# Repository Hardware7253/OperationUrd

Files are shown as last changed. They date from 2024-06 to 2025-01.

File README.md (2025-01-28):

# Operation Urd
A nixie tube clock inspired by the divergence meter from Steins;Gate.

Designed in KiCad and Onshape, programmed in Rust.

tough_pic_1
tough_pic_2
tough pic 3
tough pic 4

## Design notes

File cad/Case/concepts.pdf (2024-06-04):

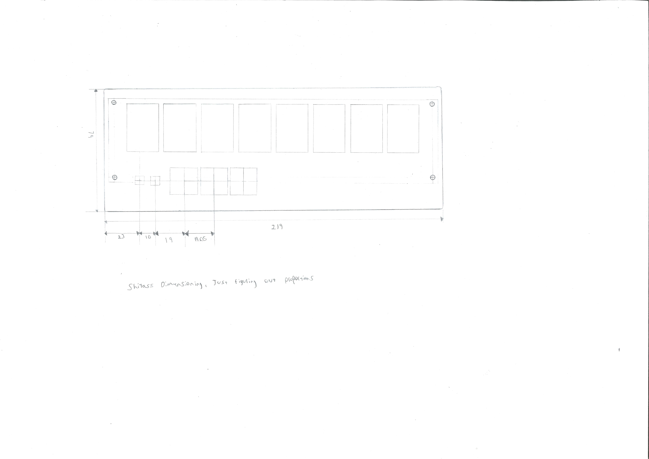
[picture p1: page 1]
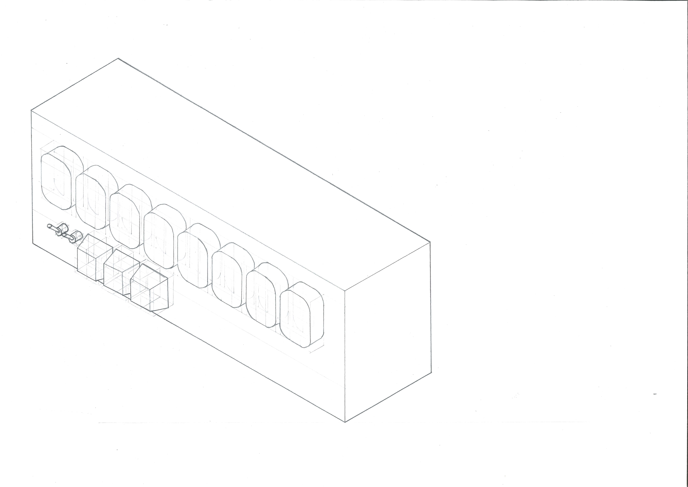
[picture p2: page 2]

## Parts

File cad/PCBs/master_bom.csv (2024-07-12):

Comment | Designator | Footprint | JLCPCB Part # | Mouser Part # | Quantity
10k |  | R_0603_1608Metric | C25804 |  | 24
MMBTA92 |  | SOT-23 | C85182 |  | 8
10k |  | R_1206_3216Metric | C17902 |  | 16
412k |  | R_1206_3216Metric | C323043 |  | 19
MMBTA42 |  | SOT-23 | C466651 |  | 19
100k |  | R_0603_1608Metric | C25803 |  | 1
~ |  | IN12 |  |  | 8
74HC595 |  | SOIC-16_3.9x9.9mm_P1.27mm | C5947 |  | 3
Conn_01x10_Pin |  | IDC-Header_2x05_P2.54mm_Vertical |  |  | 4
MAX1771ESA+T |  | SO-8_3.9x4.9mm_P1.27mm | C407903 |  | 1
68u |  | EEE-FN1E680P | C494823 |  | 1
100n/250v |  | C_1206_3216Metric | C5137643 |  | 1
IRF644PBF |  | TO-220-3_Vertical |  | 844-IRF644PBF | 1
1M5 |  | R_2512_6332Metric | C3013328 |  | 1
100n |  | C_0603_1608Metric | C14663 |  | 7
0.05R |  | R_1206_3216Metric_Pad1.30x1.75mm_HandSolder | C912768 |  | 1
100p/250v |  | C_0805_2012Metric | C2929108 |  | 1
ES2F-E3/5BT |  | D_SMB | C222525 |  | 1
100uH |  | SMDRS1275-101N | C163688 |  | 1
1u |  | C_0603_1608Metric | C15849 |  | 3
4.7u/250v |  | CP_Radial_D8.0mm_P3.50mm |  | 80-A759KS475M2EAE496 | 1
10k |  | Potentiometer_Bourns_3266W_Vertical | C123430 |  | 1
22u |  | C_0805_2012Metric | C45783 |  | 2
DS3231MZ |  | SOP-8_4.93mmxP1.27mm | C107410 |  | 1
USB_C_Receptacle |  | USB_C_Receptacle_GCT_USB4125-xx-x-0190_6P_TopMnt_Horizontal | C2927302 |  | 1
Conn_01x04_Pin |  | PinHeader_1x04_P2.54mm_Vertical |  |  | 4
14p |  | C_0603_1608Metric | C1644 |  | 2
D_Zener |  | D_SOD-323 | C5143684 |  | 1
RED |  | LED_0603_1608Metric | C2286 |  | 1
2k2 |  | R_0603_1608Metric | C4190 |  | 3
SolderJumper_2_Open |  | PinHeader_1x02_P2.54mm_Vertical |  |  | 2
5k1 |  | R_0603_1608Metric | C23186 |  | 2
Battery |  | BAT-HLD-005-THM |  | 712-BAT-HLD-005-THM | 1
10n |  | C_0603_1608Metric | C57112 |  | 1
10u |  | C_0603_1608Metric | C19702 |  | 1
120R |  | R_0603_1608Metric | C96702 |  | 1
5k-500k |  | R_LDR_5.0x4.1mm_P3mm_Vertical | C125626 |  | 1
AMS1117-3.3 |  | SOT-223-3_TabPin2 | C6186 |  | 1
STM32F103CBTx |  | LQFP-48_7x7mm_P0.5mm | C8304 |  | 1
8Mhz |  | Crystal_SMD_3225-4Pin_3.2x2.5mm | C403948 |  | 1
SW_SPST |  | MTS-101 |  |  | 2
SW_SPST |  | SW_Cherry_MX_1.00u_PCB |  |  | 3
Conn_01x04_Pin |  | PinHeader_1x04_P2.54mm_Horizontal |  |  | 1

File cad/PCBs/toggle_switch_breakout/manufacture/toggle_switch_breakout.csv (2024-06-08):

Comment | Designator | Footprint | JLCPCB Part # | Mouser Part # | Quantity
SW_SPST | SW2,SW1 | MTS-101 |  |  | 2
Conn_01x04_Pin | J1 | PinHeader_1x04_P2.54mm_Vertical |  |  | 1

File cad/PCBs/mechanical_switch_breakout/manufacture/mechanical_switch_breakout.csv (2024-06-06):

Comment | Designator | Footprint | JLCPCB Part # | Mouser Part # | Quantity
SW_SPST | SW3,SW2,SW1 | SW_Cherry_MX_1.00u_PCB |  |  | 3
Conn_01x04_Pin | J1 | PinHeader_1x04_P2.54mm_Horizontal |  |  | 1

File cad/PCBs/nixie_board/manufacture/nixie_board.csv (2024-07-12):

Comment | Designator | Footprint | JLCPCB Part # | Mouser Part # | Quantity
10k | R3,R32,R10,R9,R28,R4,R52,R8,R44,R15,R2,R13,R19,R40,R36,R56,R20,R48,R1,R14 | R_0603_1608Metric | C25804 |  | 20
MMBTA92 | Q14,Q18,Q22,Q16,Q26,Q20,Q12,Q24 | SOT-23 | C85182 |  | 8
10k | R37,R33,R51,R53,R55,R31,R41,R27,R47,R25,R49,R39,R43,R35,R45,R29 | R_1206_3216Metric | C17902 |  | 16
412k | R23,R50,R17,R26,R54,R21,R16,R38,R18,R7,R12,R30,R34,R5,R24,R11,R6,R46,R42 | R_1206_3216Metric | C323043 |  | 19
MMBTA42 | Q15,Q11,Q2,Q21,Q4,Q19,Q23,Q17,Q3,Q9,Q8,Q6,Q25,Q7,Q13,Q5,Q10,Q1,Q27 | SOT-23 | C466651 |  | 19
100k | R22 | R_0603_1608Metric | C25803 |  | 1
~ | N1,N8,N2,N3,N4,N7,N5,N6 | IN12 |  |  | 8
74HC595 | U1,U2,U3 | SOIC-16_3.9x9.9mm_P1.27mm | C5947 |  | 3
Conn_01x10_Pin | J1 | IDC-Header_2x05_P2.54mm_Vertical |  |  | 1

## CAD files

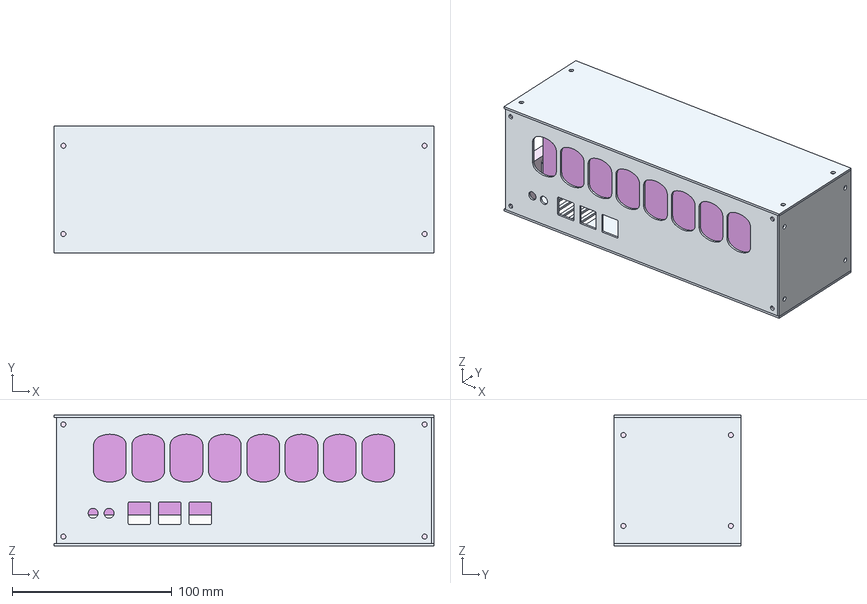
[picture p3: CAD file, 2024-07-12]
cad/Case/Urd.step
238.0 x 79.5 x 82.0 mm

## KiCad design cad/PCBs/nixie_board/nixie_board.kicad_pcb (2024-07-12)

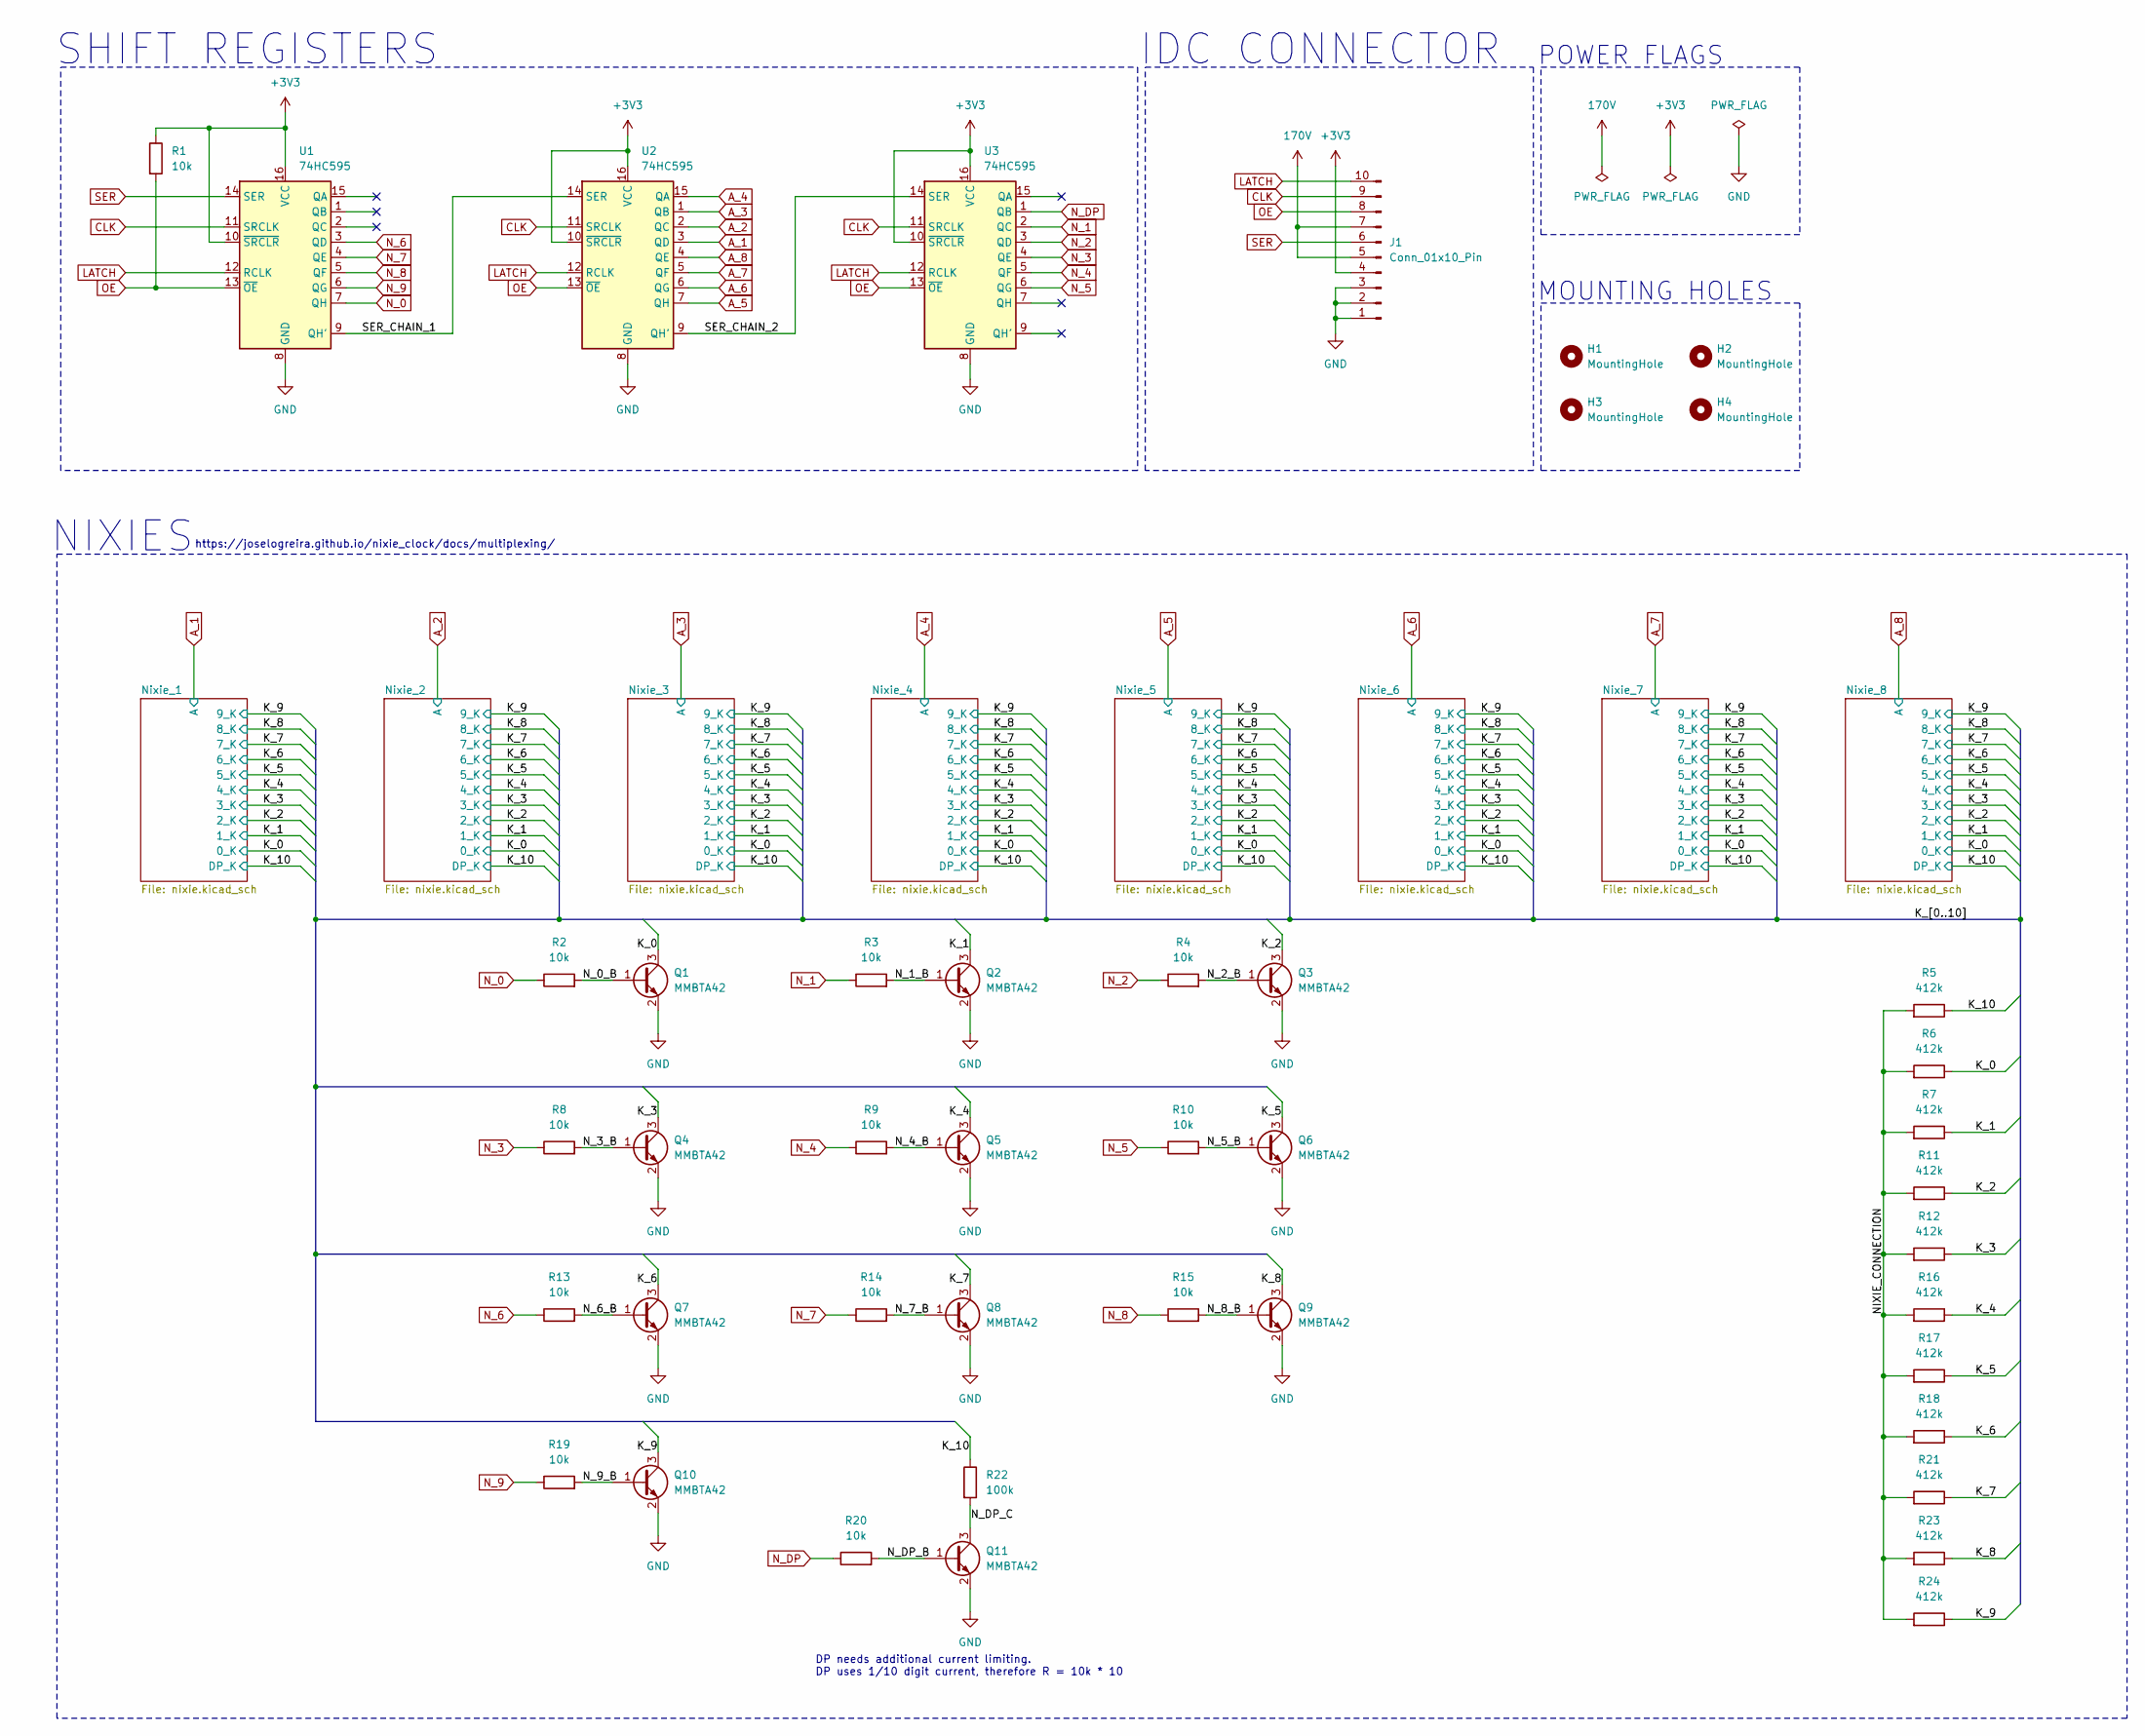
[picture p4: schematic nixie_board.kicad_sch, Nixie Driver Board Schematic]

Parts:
H1, H2, H3, H4: MountingHole; MountingHole_3.2mm_M3
J1: Conn_01x10_Pin; IDC-Header_2x05_P2.54mm_Vertical
Q1, Q2, Q3, Q4, Q5, Q6, Q7, Q8, Q9, Q10, Q11: MMBTA42; SOT-23
R1, R2, R3, R4, R8, R9, R10, R13, R14, R15, R19, R20: 10k; R_0603_1608Metric
R5, R6, R7, R11, R12, R16, R17, R18, R21, R23, R24: 412k; R_1206_3216Metric
R22: 100k; R_0603_1608Metric
U1, U2, U3: 74HC595; SOIC-16_3.9x9.9mm_P1.27mm

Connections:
170V: J1.5, J1.7; also elsewhere on the board
+3V3: J1.4, R1.1, U1.10 (~SRCLR), U1.16 (VCC), U2.10 (~SRCLR), U2.16 (VCC), U3.10 (~SRCLR), U3.16 (VCC)
/K_0: Q1.3 (C), R6.1; also elsewhere on the board
/K_1: Q2.3 (C), R7.1; also elsewhere on the board
/K_2: Q3.3 (C), R11.1; also elsewhere on the board
/K_3: Q4.3 (C), R12.1; also elsewhere on the board
/K_4: Q5.3 (C), R16.1; also elsewhere on the board
/K_5: Q6.3 (C), R17.1; also elsewhere on the board
/K_6: Q7.3 (C), R18.1; also elsewhere on the board
/K_7: Q8.3 (C), R21.1; also elsewhere on the board
/K_8: Q9.3 (C), R23.1; also elsewhere on the board
/K_9: Q10.3 (C), R24.1; also elsewhere on the board
/K_10: R5.1, R22.1; also elsewhere on the board
/NIXIE_CONNECTION: R5.2, R6.2, R7.2, R11.2, R12.2, R16.2, R17.2, R18.2, R21.2, R23.2, R24.2
/N_0_B: Q1.1 (B), R2.2
/N_1_B: Q2.1 (B), R3.2
/N_2_B: Q3.1 (B), R4.2
/N_3_B: Q4.1 (B), R8.2
/N_4_B: Q5.1 (B), R9.2
/N_5_B: Q6.1 (B), R10.2
/N_6_B: Q7.1 (B), R13.2
/N_7_B: Q8.1 (B), R14.2
/N_8_B: Q9.1 (B), R15.2
/N_9_B: Q10.1 (B), R19.2
/N_DP_B: Q11.1 (B), R20.2
/N_DP_C: Q11.3 (C), R22.2
/SER_CHAIN_1: U1.9 (QH'), U2.14 (SER)
/SER_CHAIN_2: U2.9 (QH'), U3.14 (SER)
A_1: U2.3 (QD); also elsewhere on the board
A_2: U2.2 (QC); also elsewhere on the board
A_3: U2.1 (QB); also elsewhere on the board
A_4: U2.15 (QA); also elsewhere on the board
A_5: U2.7 (QH); also elsewhere on the board
A_6: U2.6 (QG); also elsewhere on the board
A_7: U2.5 (QF); also elsewhere on the board
A_8: U2.4 (QE); also elsewhere on the board
CLK: J1.9, U1.11 (SRCLK), U2.11 (SRCLK), U3.11 (SRCLK)
GND: J1.1, J1.2, J1.3, Q1.2 (E), Q2.2 (E), Q3.2 (E), Q4.2 (E), Q5.2 (E), Q6.2 (E), Q7.2 (E), Q8.2 (E), Q9.2 (E), Q10.2 (E), Q11.2 (E), U1.8 (GND), U2.8 (GND), U3.8 (GND); also elsewhere on the board
LATCH: J1.10, U1.12 (RCLK), U2.12 (RCLK), U3.12 (RCLK)
N_0: R2.1, U1.7 (QH)
N_1: R3.1, U3.2 (QC)
N_2: R4.1, U3.3 (QD)
N_3: R8.1, U3.4 (QE)
N_4: R9.1, U3.5 (QF)
N_5: R10.1, U3.6 (QG)
N_6: R13.1, U1.3 (QD)
N_7: R14.1, U1.4 (QE)
N_8: R15.1, U1.5 (QF)
N_9: R19.1, U1.6 (QG)
N_DP: R20.1, U3.1 (QB)
OE: J1.8, R1.2, U1.13 (~OE), U2.13 (~OE), U3.13 (~OE)
SER: J1.6, U1.14 (SER)

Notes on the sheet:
SHIFT REGISTERS
https://joselogreira.github.io/nixie_clock/docs/multiplexing/
IDC CONNECTOR
MOUNTING HOLES
NIXIES
POWER FLAGS
DP needs additional current limiting. DP uses 1/10 digit current, therefore R = 10k * 10

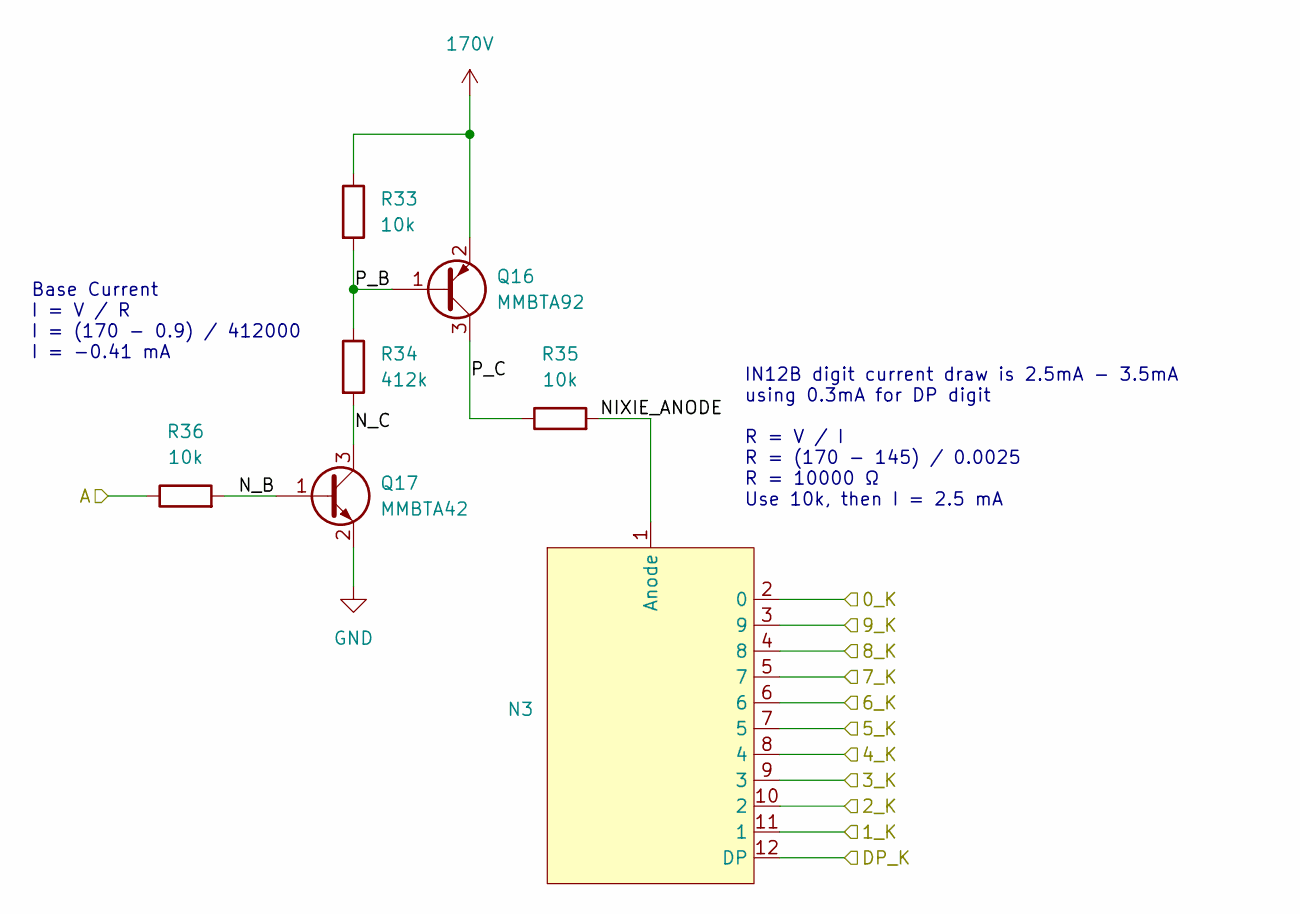
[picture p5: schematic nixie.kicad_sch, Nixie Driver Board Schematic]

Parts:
N3: IN12
Q16: MMBTA92; SOT-23
Q17: MMBTA42; SOT-23
R33, R35: 10k; R_1206_3216Metric
R34: 412k; R_1206_3216Metric
R36: 10k; R_0603_1608Metric

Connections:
170V: Q16.2 (E), R33.1; also elsewhere on the board
/K_0: N3.2 (0); also elsewhere on the board
/K_1: N3.11 (1); also elsewhere on the board
/K_2: N3.10 (2); also elsewhere on the board
/K_3: N3.9 (3); also elsewhere on the board
/K_4: N3.8 (4); also elsewhere on the board
/K_5: N3.7 (5); also elsewhere on the board
/K_6: N3.6; also elsewhere on the board
/K_7: N3.5 (7); also elsewhere on the board
/K_8: N3.4 (8); also elsewhere on the board
/K_9: N3.3 (9); also elsewhere on the board
/K_10: N3.12 (DP); also elsewhere on the board
/Nixie_3/NIXIE_ANODE: N3.1 (Anode), R35.2
/Nixie_3/N_B: Q17.1 (B), R36.2
/Nixie_3/N_C: Q17.3 (C), R34.2
/Nixie_3/P_B: Q16.1 (B), R33.2, R34.1
/Nixie_3/P_C: Q16.3 (C), R35.1
A_3: R36.1; also elsewhere on the board
GND: Q17.2 (E); also elsewhere on the board

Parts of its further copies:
N1, N2, N4, N5, N6, N7, N8: IN12
Q12, Q14, Q18, Q20, Q22, Q24, Q26: MMBTA92; SOT-23
Q13, Q15, Q19, Q21, Q23, Q25, Q27: MMBTA42; SOT-23
R25, R27, R29, R31, R37, R39, R41, R43, R45, R47, R49, R51, R53, R55: 10k; R_1206_3216Metric
R26, R30, R38, R42, R46, R50, R54: 412k; R_1206_3216Metric
R28, R32, R40, R44, R48, R52, R56: 10k; R_0603_1608Metric

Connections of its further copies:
170V: Q12.2 (E), Q14.2 (E), Q18.2 (E), Q20.2 (E), Q22.2 (E), Q24.2 (E), Q26.2 (E), R25.1, R29.1, R37.1, R41.1, R45.1, R49.1, R53.1; also elsewhere on the board
/K_0: N1.2 (0), N2.2 (0), N4.2 (0), N5.2 (0), N6.2 (0), N7.2 (0), N8.2 (0); also elsewhere on the board
/K_1: N1.11 (1), N2.11 (1), N4.11 (1), N5.11 (1), N6.11 (1), N7.11 (1), N8.11 (1); also elsewhere on the board
/K_2: N1.10 (2), N2.10 (2), N4.10 (2), N5.10 (2), N6.10 (2), N7.10 (2), N8.10 (2); also elsewhere on the board
/K_3: N1.9 (3), N2.9 (3), N4.9 (3), N5.9 (3), N6.9 (3), N7.9 (3), N8.9 (3); also elsewhere on the board
/K_4: N1.8 (4), N2.8 (4), N4.8 (4), N5.8 (4), N6.8 (4), N7.8 (4), N8.8 (4); also elsewhere on the board
/K_5: N1.7 (5), N2.7 (5), N4.7 (5), N5.7 (5), N6.7 (5), N7.7 (5), N8.7 (5); also elsewhere on the board
/K_6: N1.6, N2.6, N4.6, N5.6, N6.6, N7.6, N8.6; also elsewhere on the board
/K_7: N1.5 (7), N2.5 (7), N4.5 (7), N5.5 (7), N6.5 (7), N7.5 (7), N8.5 (7); also elsewhere on the board
/K_8: N1.4 (8), N2.4 (8), N4.4 (8), N5.4 (8), N6.4 (8), N7.4 (8), N8.4 (8); also elsewhere on the board
/K_9: N1.3 (9), N2.3 (9), N4.3 (9), N5.3 (9), N6.3 (9), N7.3 (9), N8.3 (9); also elsewhere on the board
/K_10: N1.12 (DP), N2.12 (DP), N4.12 (DP), N5.12 (DP), N6.12 (DP), N7.12 (DP), N8.12 (DP); also elsewhere on the board
/Nixie_1/NIXIE_ANODE: N1.1 (Anode), R27.2
/Nixie_1/N_B: Q13.1 (B), R28.2
/Nixie_1/N_C: Q13.3 (C), R26.2
/Nixie_1/P_B: Q12.1 (B), R25.2, R26.1
/Nixie_1/P_C: Q12.3 (C), R27.1
/Nixie_2/NIXIE_ANODE: N2.1 (Anode), R31.2
/Nixie_2/N_B: Q15.1 (B), R32.2
/Nixie_2/N_C: Q15.3 (C), R30.2
/Nixie_2/P_B: Q14.1 (B), R29.2, R30.1
/Nixie_2/P_C: Q14.3 (C), R31.1
/Nixie_4/NIXIE_ANODE: N4.1 (Anode), R39.2
/Nixie_4/N_B: Q19.1 (B), R40.2
/Nixie_4/N_C: Q19.3 (C), R38.2
/Nixie_4/P_B: Q18.1 (B), R37.2, R38.1
/Nixie_4/P_C: Q18.3 (C), R39.1
/Nixie_5/NIXIE_ANODE: N5.1 (Anode), R43.2
/Nixie_5/N_B: Q21.1 (B), R44.2
/Nixie_5/N_C: Q21.3 (C), R42.2
/Nixie_5/P_B: Q20.1 (B), R41.2, R42.1
/Nixie_5/P_C: Q20.3 (C), R43.1
/Nixie_6/NIXIE_ANODE: N6.1 (Anode), R47.2
/Nixie_6/N_B: Q23.1 (B), R48.2
/Nixie_6/N_C: Q23.3 (C), R46.2
/Nixie_6/P_B: Q22.1 (B), R45.2, R46.1
/Nixie_6/P_C: Q22.3 (C), R47.1
/Nixie_7/NIXIE_ANODE: N7.1 (Anode), R51.2
/Nixie_7/N_B: Q25.1 (B), R52.2
/Nixie_7/N_C: Q25.3 (C), R50.2
/Nixie_7/P_B: Q24.1 (B), R49.2, R50.1
/Nixie_7/P_C: Q24.3 (C), R51.1
/Nixie_8/NIXIE_ANODE: N8.1 (Anode), R55.2
/Nixie_8/N_B: Q27.1 (B), R56.2
/Nixie_8/N_C: Q27.3 (C), R54.2
/Nixie_8/P_B: Q26.1 (B), R53.2, R54.1
/Nixie_8/P_C: Q26.3 (C), R55.1
A_1: R28.1; also elsewhere on the board
A_2: R32.1; also elsewhere on the board
A_4: R40.1; also elsewhere on the board
A_5: R44.1; also elsewhere on the board
A_6: R48.1; also elsewhere on the board
A_7: R52.1; also elsewhere on the board
A_8: R56.1; also elsewhere on the board
GND: Q13.2 (E), Q15.2 (E), Q19.2 (E), Q21.2 (E), Q23.2 (E), Q25.2 (E), Q27.2 (E); also elsewhere on the board

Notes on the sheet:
Base Current I = V / R I = (170 - 0.9) / 412000 I = -0.41 mA
IN12B digit current draw is 2.5mA - 3.5mA using 0.3mA for DP digit R = V / I R = (170 - 145) / 0.0025 R = 10000 Ω Use 10k, then I = 2.5 mA

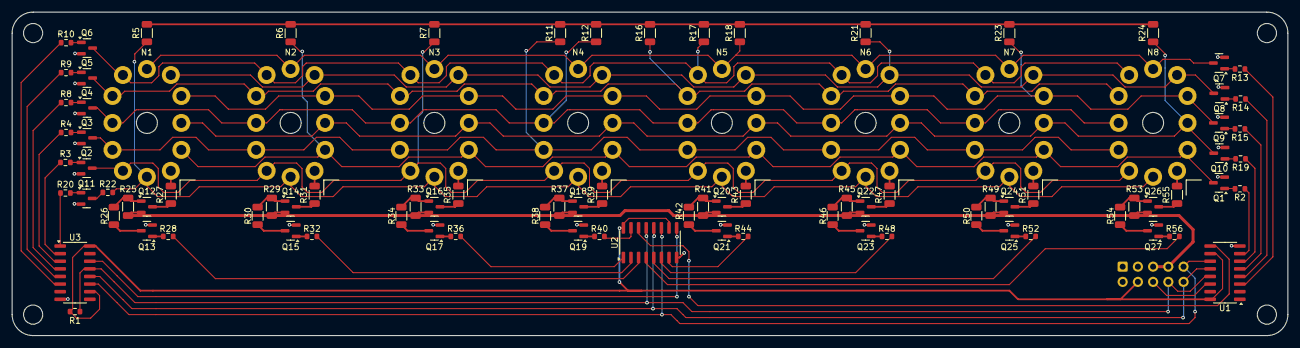
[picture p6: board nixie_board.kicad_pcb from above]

Board: 2 copper layers, 213.0 x 54.0 mm, 99 parts (1 on the bottom side), 92 nets.

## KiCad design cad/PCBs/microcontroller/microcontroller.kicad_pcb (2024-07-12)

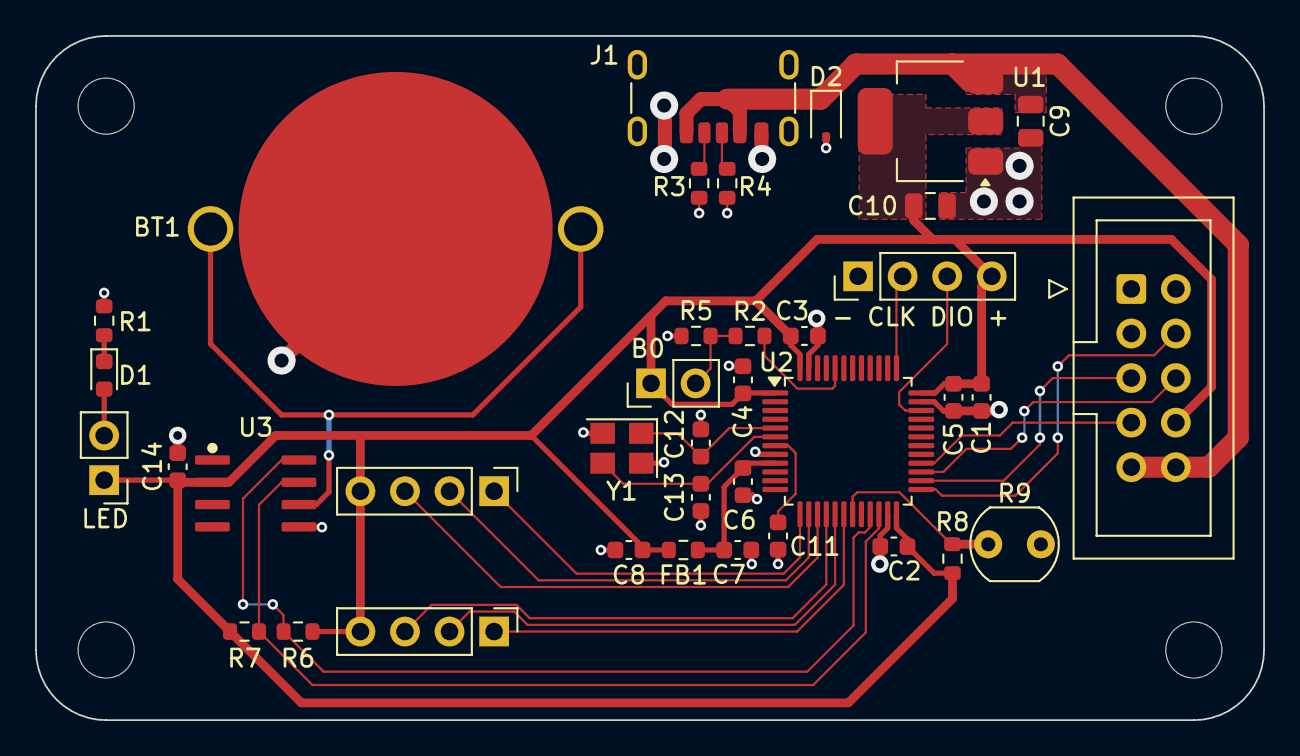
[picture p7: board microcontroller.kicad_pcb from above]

Board: 2 copper layers, 70.0 x 39.0 mm, 42 parts (0 on the bottom side), 29 nets.

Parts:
BT1: Battery; BAT-HLD-005-THM
C1: 10u; C_0603_1608Metric
C2, C3, C4, C5, C11, C14: 100n; C_0603_1608Metric
C6: 10n; C_0603_1608Metric
C7, C8: 1u; C_0603_1608Metric
C9, C10: 22u; C_0805_2012Metric
C12, C13: 14p; C_0603_1608Metric
D1: RED; LED_0603_1608Metric
D2: D_Zener; D_SOD-323
FB1: 120R; R_0603_1608Metric
H1, H2, H3, H4: MountingHole; MountingHole_3.2mm_M3
J1: USB_C_Receptacle; USB_C_Receptacle_GCT_USB4125-xx-x-0190_6P_TopMnt_Horizontal
J2, J3, J4: Conn_01x04_Pin; PinHeader_1x04_P2.54mm_Vertical
J5: Conn_01x10_Pin; IDC-Header_2x05_P2.54mm_Vertical
JP1, JP2: SolderJumper_2_Open; PinHeader_1x02_P2.54mm_Vertical
R1, R6, R7: 2k2; R_0603_1608Metric
R2, R5, R8: 10k; R_0603_1608Metric
R3, R4: 5k1; R_0603_1608Metric
R9: 5k-500k; R_LDR_5.0x4.1mm_P3mm_Vertical
U1: AMS1117-3.3; SOT-223-3_TabPin2
U2: STM32F103CBTx; LQFP-48_7x7mm_P0.5mm
U3: DS3231MZ; SOP-8_4.93mmxP1.27mm
Y1: 8Mhz; Crystal_SMD_3225-4Pin_3.2x2.5mm

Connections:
+3.3VA: C6.1, C7.1, FB1.1, U2.9 (VDDA)
+3V3: C1.1, C2.1, C3.1, C4.1, C5.1, C8.1, C10.1, C14.1, FB1.2, J2.4, J3.4, J4.4, J5.8, JP1.1 (A), JP2.1 (A), R6.2, R7.2, R8.1, U1.2 (VO), U2.1 (VBAT), U2.24 (VDD), U2.36 (VDD), U2.48 (VDD), U3.2 (VCC)
+BATT: BT1.1 (+), U3.6 (VBAT)
/BOOT0: R2.1, U2.44 (BOOT0)
/JMP_BOOT0: JP2.2 (B), R2.2, R5.2
/NRST: C11.1, U2.7 (NRST)
/PWR_LED_A: D1.2 (A), JP1.2 (B)
/PWR_LED_K: D1.1 (K), R1.1
/SWCLK: J2.2, U2.37 (PA14)
/SWDIO: J2.3, U2.34 (PA13)
CLK: J5.5, U2.26 (PB13)
GND: BT1.2 (-), C1.2, C2.2, C3.2, C4.2, C5.2, C6.2, C7.2, C8.2, C9.2, C10.2, C11.2, C12.2, C13.2, C14.2, D2.2 (A), J1.A12 (GND), J1.B12 (GND), J2.1, J5.1, J5.2, J5.3, R1.2, R3.1, R4.1, R5.1, R9.2, U1.1 (GND), U2.8 (VSSA), U2.23 (VSS), U2.35 (VSS), U2.47 (VSS), U3.5 (GND), Y1.2, Y1.4
HSE_IN: C12.1, U2.5 (PD0), Y1.1
HSE_OUT: C13.1, U2.6 (PD1), Y1.3
LATCH: J5.4, U2.25 (PB12)
LDR: R8.2, R9.1, U2.19 (PB1)
MECH_SW_1: J4.1, U2.13 (PA3)
MECH_SW_2: J4.2, U2.14 (PA4)
MECH_SW_3: J4.3, U2.15 (PA5)
unnamed: J1.A5 (CC1), R4.2
unnamed: J1.B5 (CC2), R3.2
OE: J5.6, U2.27 (PB14)
SCL: R6.1, U2.21 (PB10), U3.8 (SCL)
SDA: R7.1, U2.22 (PB11), U3.7 (SDA)
SER: J5.7, U2.28 (PB15)
TOGGLE_SW_1: J3.1, U2.18 (PB0)
TOGGLE_SW_2: J3.2, U2.17 (PA7)
TOGGLE_SW_3: J3.3, U2.16 (PA6)
VBUS: C9.1, D2.1 (K), J1.A9 (VBUS), J1.B9 (VBUS), J5.9, J5.10, U1.3 (VI)

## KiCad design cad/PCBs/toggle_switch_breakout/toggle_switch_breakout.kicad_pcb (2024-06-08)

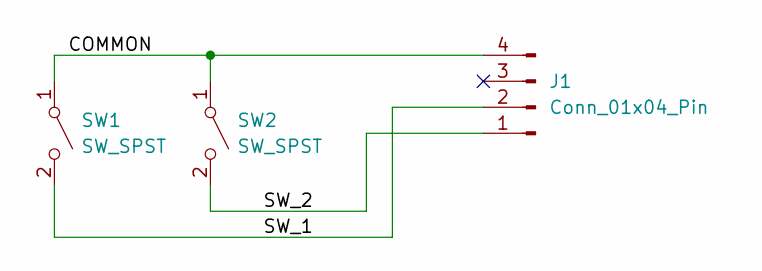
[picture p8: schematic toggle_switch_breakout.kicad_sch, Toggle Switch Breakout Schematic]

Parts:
J1: Conn_01x04_Pin; PinHeader_1x04_P2.54mm_Vertical
SW1, SW2: SW_SPST; MTS-101

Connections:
/COMMON: J1.4, SW1.1 (A), SW2.1 (A)
/SW_1: J1.2, SW1.2 (B)
/SW_2: J1.1, SW2.2 (B)

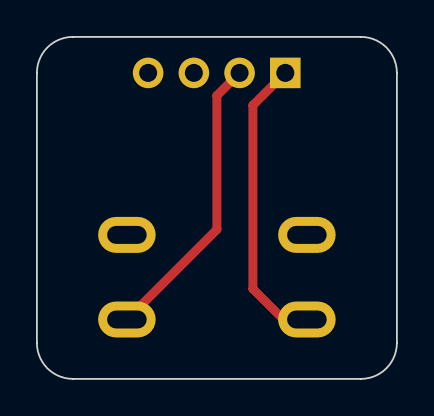
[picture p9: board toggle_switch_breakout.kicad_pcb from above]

Board: 2 copper layers, 20.0 x 19.0 mm, 3 parts (1 on the bottom side), 3 nets.

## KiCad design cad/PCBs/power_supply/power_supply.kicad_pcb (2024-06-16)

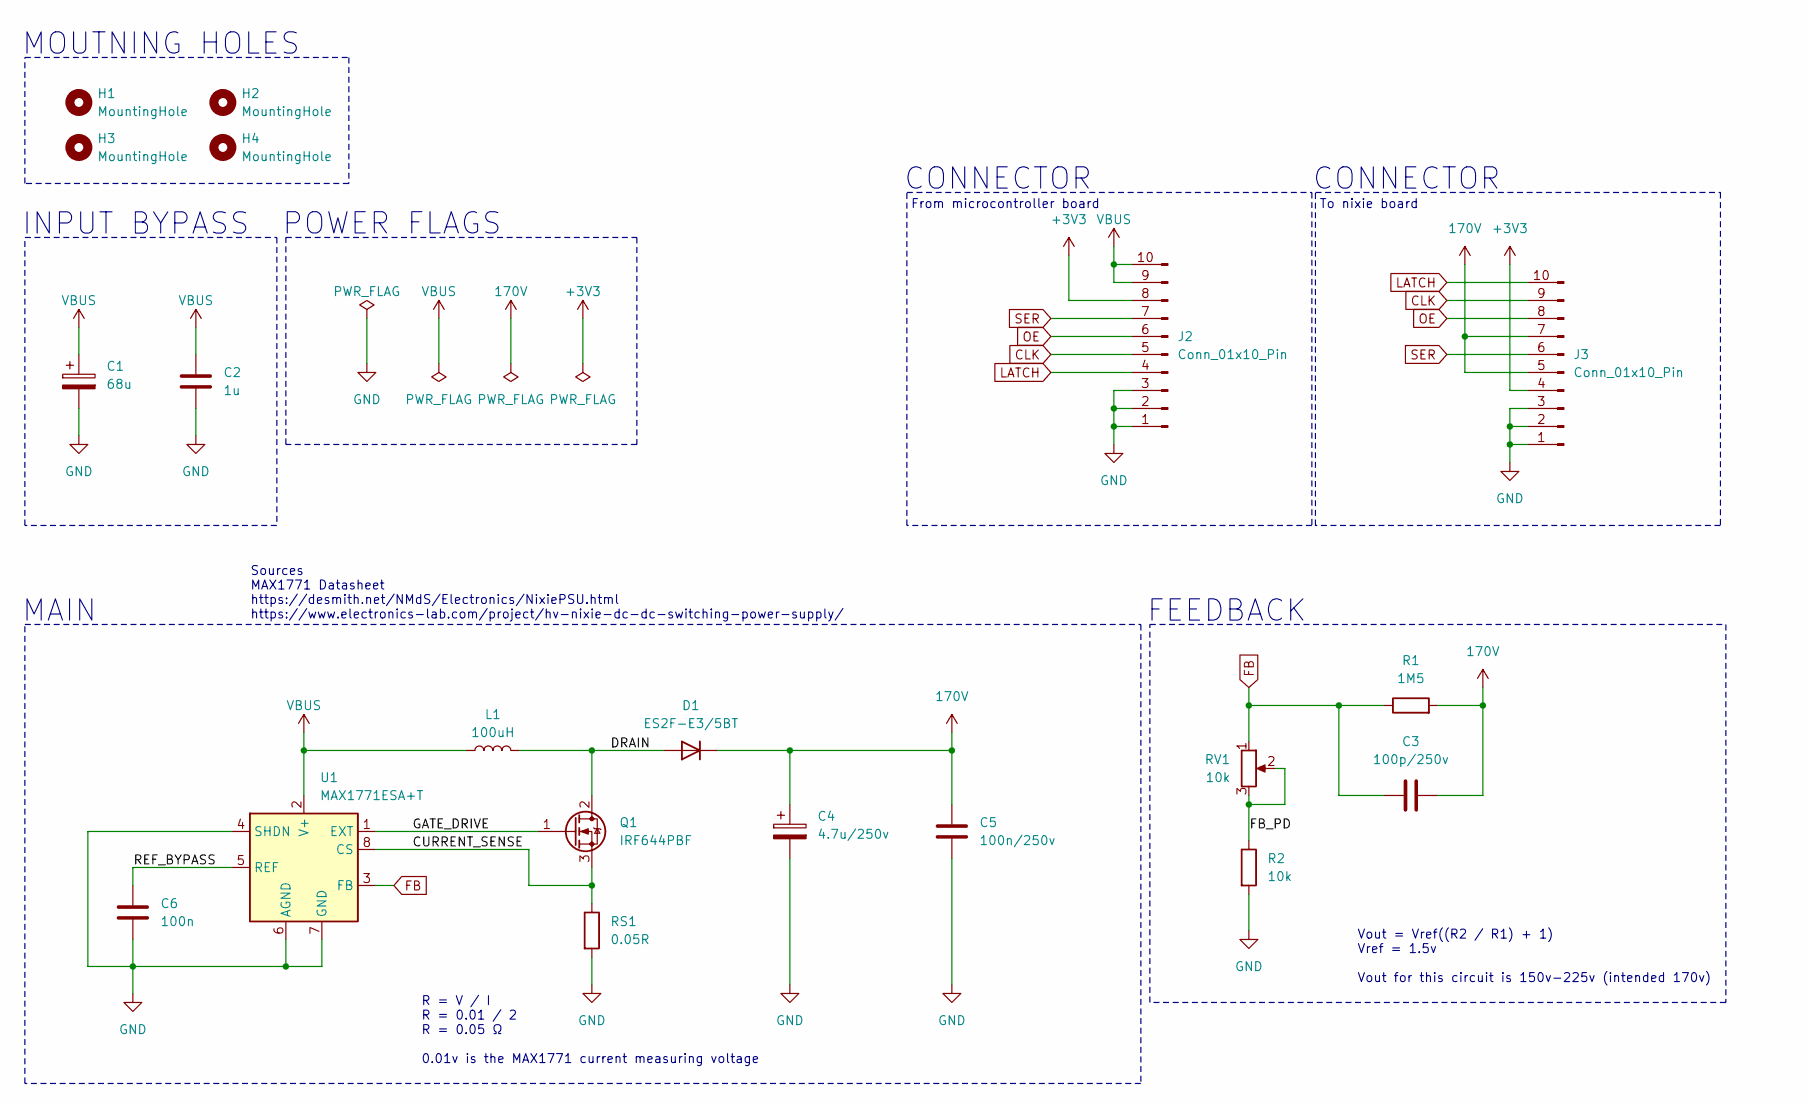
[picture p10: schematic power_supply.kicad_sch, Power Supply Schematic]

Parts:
C1: 68u; EEE-FN1E680P
C2: 1u; C_0603_1608Metric
C3: 100p/250v; C_0805_2012Metric
C4: 4.7u/250v; CP_Radial_D8.0mm_P3.50mm
C5: 100n/250v; C_1206_3216Metric
C6: 100n; C_0603_1608Metric
D1: ES2F-E3/5BT; D_SMB
H1, H2, H3, H4: MountingHole; MountingHole_3.2mm_M3
J2, J3: Conn_01x10_Pin; IDC-Header_2x05_P2.54mm_Vertical
L1: 100uH; SMDRS1275-101N
Q1: IRF644PBF; TO-220-3_Vertical
R1: 1M5; R_2512_6332Metric
R2: 10k; R_0603_1608Metric
RS1: 0.05R; R_1206_3216Metric_Pad1.30x1.75mm_HandSolder
RV1: 10k; Potentiometer_Bourns_3266W_Vertical
U1: MAX1771ESA+T; SO-8_3.9x4.9mm_P1.27mm

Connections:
170V: C3.2, C4.1, C5.1, D1.1 (K), J3.5, J3.7, R1.2
+3V3: J2.8, J3.4
/CURRENT_SENSE: Q1.3 (S), RS1.1, U1.8 (CS)
/DRAIN: D1.2 (A), L1.2, Q1.2 (D)
/FB_PD: R2.1, RV1.2, RV1.3
/GATE_DRIVE: Q1.1 (G), U1.1 (EXT)
/REF_BYPASS: C6.1, U1.5 (REF)
CLK: J2.5, J3.9
FB: C3.1, R1.1, RV1.1, U1.3 (FB)
GND: C1.2, C2.2, C4.2, C5.2, C6.2, J2.1, J2.2, J2.3, J3.1, J3.2, J3.3, R2.2, RS1.2, U1.4 (SHDN), U1.6 (AGND), U1.7 (GND)
LATCH: J2.4, J3.10
OE: J2.6, J3.8
SER: J2.7, J3.6
VBUS: C1.1, C2.1, J2.9, J2.10, L1.1, U1.2 (V+)

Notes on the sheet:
MOUTNING HOLES
From microcontroller board
R = V / I R = 0.01 / 2 R = 0.05 Ω 0.01v is the MAX1771 current measuring voltage
CONNECTOR
Vout = Vref((R2 / R1) + 1) Vref = 1.5v Vout for this circuit is 150v-225v (intended 170v)
INPUT BYPASS
Sources MAX1771 Datasheet https://desmith.net/NMdS/Electronics/NixiePSU.html https://www.electronics-lab.com/project/hv-nixie-dc-dc-switching-power-supply/
FEEDBACK
To nixie board
POWER FLAGS
MAIN

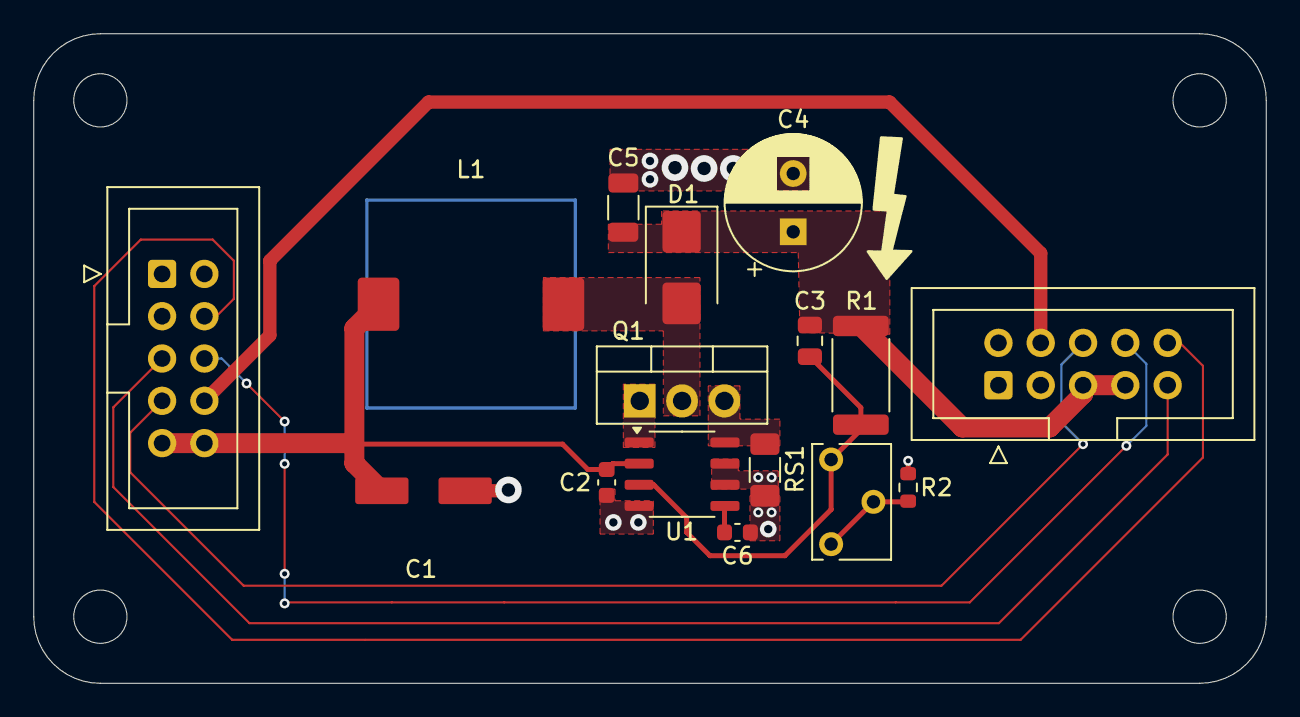
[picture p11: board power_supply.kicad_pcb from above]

Board: 2 copper layers, 74.0 x 39.0 mm, 20 parts (0 on the bottom side), 14 nets.

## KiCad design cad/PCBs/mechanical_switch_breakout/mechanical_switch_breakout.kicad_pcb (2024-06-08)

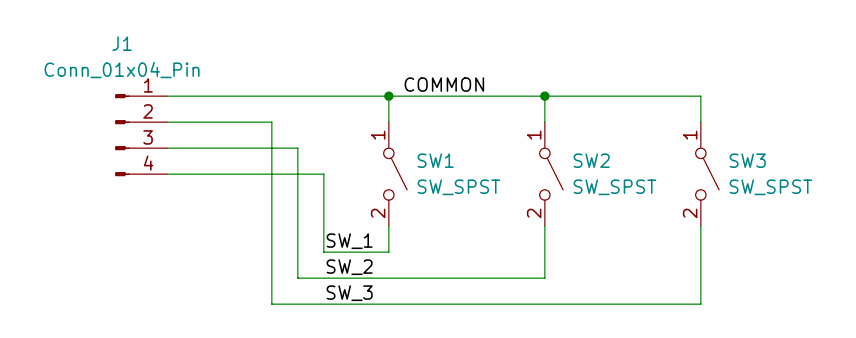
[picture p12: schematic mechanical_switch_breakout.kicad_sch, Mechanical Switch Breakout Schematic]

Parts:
J1: Conn_01x04_Pin; PinHeader_1x04_P2.54mm_Horizontal
SW1, SW2, SW3: SW_SPST; SW_Cherry_MX_1.00u_PCB

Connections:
/COMMON: J1.1, SW1.1 (A), SW2.1 (A), SW3.1 (A)
/SW_1: J1.4, SW1.2 (B)
/SW_2: J1.3, SW2.2 (B)
/SW_3: J1.2, SW3.2 (B)

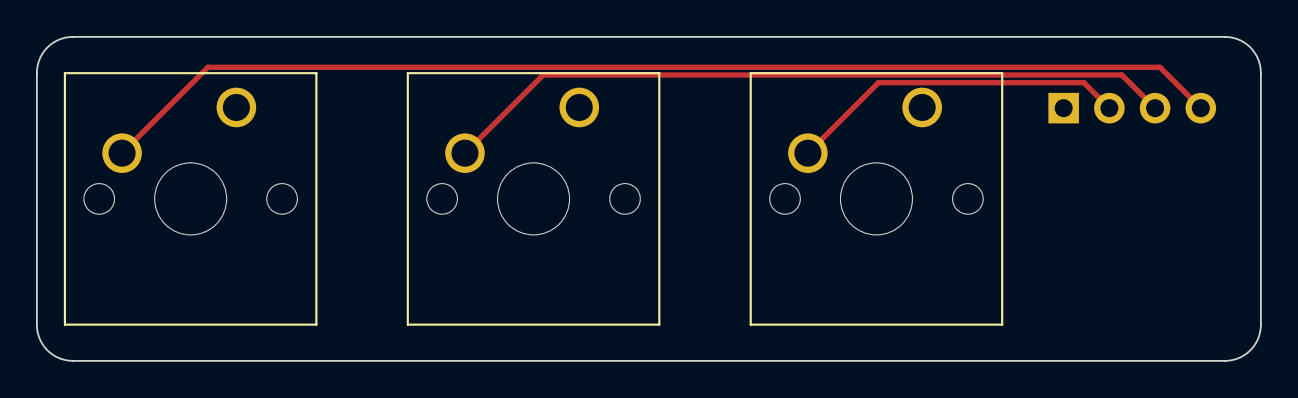
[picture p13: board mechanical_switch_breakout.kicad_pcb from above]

Board: 2 copper layers, 68.0 x 18.0 mm, 4 parts (1 on the bottom side), 4 nets.

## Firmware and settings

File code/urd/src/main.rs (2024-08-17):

// This program turns the led on and off, and prints the current state of the led

#![no_std]
#![no_main]

use panic_rtt_core::{self, rtt_init_print, rprintln};

use cortex_m_rt::entry;
use stm32f1xx_hal as hal;
use hal::{
    pac,
    i2c::{BlockingI2c, DutyCycle, Mode as Mode_i2c},
    spi::*,
    prelude::*
};

use ds323x::{DateTimeAccess, Ds323x, Rtcc, Timelike};

use arrform::{arrform, ArrForm};
use rand::{Rng, SeedableRng};
use rand::rngs::SmallRng;

pub mod cycle_counter;
pub mod nixies;
pub mod button;
pub mod helpers;

use helpers::{add_with_rollover, ms_to_cycles};

const DIVERGENCE_NUMBERS: [&'static str; 21] = [
    // Alpha
    "0.337187",
    "0.409420",
    "0.409431",
    "0.456903",
    "0.456914",
    "0.523299",
    "0.523307",
    "0.571015",
    "0.571046",
    "0.571082",

    // Beta
    "1.053649",
    "1.055821",
    "1.064750",
    "1.064756",
    "1.129848",
    "1.129954",
    "1.130205",
    "1.130238",
    "1.130426",
    "1.143688",
    "1.382733",
];

const CLOCK_MHZ: u32 = 72;

const ANTI_POISON_INTERVAL_MS: u64 = 10 * 60 * 1000; // 10 Minutes between anti poison routines
const ANTI_POISON_DURATION_MS: u64 = 15 * 1000; // Anti poison routines last for 15 seconds
const ANIT_POISON_PATTERN: [usize; 8] = [3, 1, 4, 0, 6, 2, 7, 5]; // What character each display starts showing during the anti poison routine
//const ANIT_POISON_PATTERN: [usize; 8] = [0, 1, 2, 3, 4, 5, 6, 7]; // This pattern creates a wave

#[entry]
fn main() -> ! {
    rtt_init_print!();

    let mut cp = cortex_m::Peripherals::take().unwrap(); // Core peripherals
    let dp = pac::Peripherals::take().unwrap(); // Device peripherals

    // Take ownership over the raw flash and rcc devices and convert them into the corresponding HAL structs
    let mut flash = dp.FLASH.constrain();
    let rcc = dp.RCC.constrain(); 

    // Freeze the configuration of all the clocks in the system and store the frozen frequencies in `clocks`
    let clocks = rcc.cfgr
        // External oscillator
        .use_hse(8.MHz())

        // Bus and core clocks
        .hclk(CLOCK_MHZ.MHz())
        .sysclk(CLOCK_MHZ.MHz())

        // Peripheral clocks
        .pclk1(12.MHz())
        .pclk2(12.MHz())
    .freeze(&mut flash.acr);
    
    let mut delay = cp.SYST.delay(&clocks);

    // Enable cycle counter
    cp.DCB.enable_trace();
    cp.DWT.enable_cycle_counter();

    let mut gpioa = dp.GPIOA.split();
    let mut gpiob = dp.GPIOB.split();
    


    // Construct rtc using i2c bus
    let scl = gpiob.pb10.into_alternate_open_drain(&mut gpiob.crh);
    let sda = gpiob.pb11.into_alternate_open_drain(&mut gpiob.crh);

    let i2c = BlockingI2c::i2c2(
        dp.I2C2,
        (scl, sda),
        Mode_i2c::Fast {
            frequency: 400.kHz(),
            duty_cycle: DutyCycle::Ratio16to9,
        },
        clocks,
        1000,
        10,
        1000,
        1000,
    );

    let mut rtc = Ds323x::new_ds3231(i2c);



    // Construct nixies using spi bus
    let spi_pins = (
        gpiob.pb13.into_alternate_push_pull(&mut gpiob.crh), // Clock
        NoMiso, // Miso
        gpiob.pb15.into_alternate_push_pull(&mut gpiob.crh)// Mosi
    );

    let spi_mode = Mode {
        polarity: Polarity::IdleLow,
        phase: Phase::CaptureOnFirstTransition,
    };

    let spi = Spi::spi2(dp.SPI2, spi_pins, spi_mode, 100.kHz(), clocks);

    let mut nixies = nixies::Nixies {
        spi_bus: spi,
        latch_pin: gpiob.pb12.into_push_pull_output(&mut gpiob.crh),
        oe_pin: gpiob.pb14.into_open_drain_output(&mut gpiob.crh),
    };

    nixies.turn_off(&mut delay);



    // Create a cycle counter struct to accurately keep track of elapsed clock cycles
    let mut cycle_counter = cycle_counter::Counter::new();

    // Setup switch pins has pulldown
    let on_switch_pin = gpioa.pa7.into_pull_down_input(&mut gpioa.crl);
    let mode_switch_pin = gpiob.pb0.into_pull_down_input(&mut gpiob.crl);

    // Buttons for adjusting the time
    let mut buttons = (
        button::Button::new(gpioa.pa3.into_pull_down_input(&mut gpioa.crl)), // Adjust hours
        button::Button::new(gpioa.pa4.into_pull_down_input(&mut gpioa.crl)), // Adjust minutes
        button::Button::new(gpioa.pa5.into_pull_down_input(&mut gpioa.crl)), // Adjust seconds
    );

    let mut time_adjust; // True when the users wants to adjust the clock time
    let mut can_exit_time_adjust = false;
    let mut divergence_index = 0; // Current index for the DIVERGENCE_NUMBERS constant

    // How many clock cyclces have to be elapsed before the anti-poison routine starts
    // This is reset after each anti-poison routine
    let mut activate_anti_posion_cycles = 0;

    loop {
        if on_switch_pin.is_high() { // Only do nixie stuff when the on switch is high
            cycle_counter.update();

            // When the cycle count exceeds activate_anti_posion_cycles then start the anti-poison routine
            if cycle_counter.cycles > activate_anti_posion_cycles {
                let deactivate_anti_posion_cycles = cycle_counter.cycles + ms_to_cycles(ANTI_POISON_DURATION_MS, CLOCK_MHZ as u64);

                // Randomise the divergence index
                let mut small_rng = SmallRng::seed_from_u64(cycle_counter.cycles);
                divergence_index = small_rng.gen_range(0..DIVERGENCE_NUMBERS.len());
                
                let mut increasing = [true; 8]; // Indicates wether the character index for each nixe is increasing or decreasing
                let mut current_indices = ANIT_POISON_PATTERN; // Current character index for each nixie

                // Anti poison routine
                // Lights each cathode in order
                while cycle_counter.cycles < deactivate_anti_posion_cycles {
                    cycle_counter.update();

                    // Update indices
                    for i in 0..nixies::SELECT_BITS.len() {
                        
                        // Increase ALL_NIXIE_CHARACTERS index for next iteration
                        let mut new_index = if increasing[i] {
                            current_indices[i] as i32 + 1
                        } else {
                            current_indices[i] as i32 - 1
                        };

                        if new_index < 0  {
                            new_index = 1;
                            increasing[i] = true;
                        }

                        if new_index > nixies::ALL_NIXIE_CHARACTERS.len() as i32 - 1 {
                            new_index = nixies::ALL_NIXIE_CHARACTERS.len() as i32 - 2;
                            increasing[i] = false;
                        }

                        current_indices[i] = new_index as usize;
                    }

                    // Display
                    for _ in 0..7 {
                        for i in 0..nixies::SELECT_BITS.len() {
                            nixies.write_char(nixies::ALL_NIXIE_CHARACTERS[current_indices[i]], i, &mut delay);
                            delay.delay_ms(1u32);
                        }
                    }
                }

                activate_anti_posion_cycles = cycle_counter.cycles + ms_to_cycles(ANTI_POISON_INTERVAL_MS, CLOCK_MHZ as u64); // Reset timer
            }

            if mode_switch_pin.is_high() {
                nixies.display_str(DIVERGENCE_NUMBERS[divergence_index], &mut delay); // Display divergence number
            } else {
                cycle_counter.update();

                // Update button structs
                buttons.0.pressed(cycle_counter.cycles);
                buttons.1.pressed(cycle_counter.cycles);
                buttons.2.pressed(cycle_counter.cycles);

                // Prevent time adjust mode being reactivated immedeately after leaving time adjust mode
                // Because the buttons would still all be registering a long press
                if (!buttons.0.press_raw || !buttons.1.press_raw || !buttons.2.press_raw) && can_exit_time_adjust {
                    can_exit_time_adjust = false;
                }

                // If all 3 buttons are held down activate time adjust mode
                time_adjust = buttons.0.long_press && buttons.1.long_press && buttons.2.long_press && !can_exit_time_adjust;


                
                // Read time from rtc
                let time = rtc.time().unwrap();
                let mut hour = time.hour();
                let mut minute = time.minute();
                let mut second = time.second();



                // Run time adjust mode in a while loop to prevent the rtc from incrementing the hours, minutes, or seconds while the user is trying to adjust.
                while time_adjust {
                    cycle_counter.update();

                    // Update button structs
                    let button_0_pressed = buttons.0.pressed(cycle_counter.cycles);
                    let button_1_pressed = buttons.1.pressed(cycle_counter.cycles);
                    let button_2_pressed = buttons.2.pressed(cycle_counter.cycles);

                    // Once any button is released it becomes possible for the user to exit time adjust mode
                    if (!buttons.0.press_raw || !buttons.1.press_raw || !buttons.2.press_raw) && !can_exit_time_adjust {
                        can_exit_time_adjust = true;
                    }

                    // If the user activates another long press exit time adjust mode
                    if buttons.0.long_press && buttons.1.long_press && buttons.2.long_press && can_exit_time_adjust {
                        time_adjust = false;
                    }

                    // Increment hours minutes and seconds when their respective buttons are pressed
                    if button_0_pressed && !buttons.1.press_raw && !buttons.2.press_raw {
                        hour = add_with_rollover(hour, 1, 0, 23);
                    }

                    if button_1_pressed && !buttons.2.press_raw && !buttons.0.press_raw {
                        minute = add_with_rollover(minute, 1, 0, 59);
                    }

                    if button_2_pressed && !buttons.0.press_raw && !buttons.1.press_raw {
                        second = add_with_rollover(second, 1, 0, 59);
                    }

                    // Update rtc datetime
                    if button_0_pressed || button_1_pressed || button_2_pressed {
                        let datetime = rtc.date()
                        .unwrap()
                        .and_hms_opt(hour, minute, second)
                        .unwrap();
                        rtc.set_datetime(&datetime).unwrap();
                    }

                    // Dsiplay adjusted time
                    let time_af = arrform!(64, "{}{} {}{} {}{}", 
                        hour / 10, hour % 10,
                        minute / 10, minute % 10,
                        second / 10, second % 10,
                    );

                    nixies.display_str(time_af.as_str(), &mut delay);
                }

                // Display time
                let time_af = arrform!(64, "{}{}.{}{}.{}{}", 
                        hour / 10, hour % 10,
                        minute / 10, minute % 10,
                        second / 10, second % 10,
                );

                nixies.display_str(time_af.as_str(), &mut delay);
            }
        } else {
            nixies.turn_off(&mut delay);
        }
    }
}

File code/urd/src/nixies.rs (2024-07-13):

// This module is for the transmission of data to the nixie tube shift registers

use stm32f1xx_hal as hal;
use hal::{
    gpio::{Pin, Output, PushPull, OpenDrain, Alternate},
    spi::*,
    timer::SysDelay,
    prelude::*
};

// All possible characters which can be displayed on the tubes
// Presented in the array in the order they are placed within the tube
pub const ALL_NIXIE_CHARACTERS: [char; 11] = ['1', '2', '6', '7', '5', '0', '4', '9', '8', '3', '.'];


// Struct contains pins and spi bus which are used to interface with the VFD display
pub struct Nixies<I: Instance, R, const P1: char, const P2: char, const C: u8, const D: u8, const L: u8, const O: u8> {
    pub spi_bus: Spi<I, R, (Pin<P1, C, Alternate>, NoMiso, Pin<P1, D, Alternate>), u8>, // Spi bus which the shift registers are attached to

    // Latch and output enable pin are on the same pin bank
    pub latch_pin: Pin<P2, L, Output<PushPull>>,
    pub oe_pin: Pin<P2, O, Output<OpenDrain>>, // OE pin should use an open drain because it has an external pullup resistor, OE is active low
}

// Represents which bit needs to be on (in the shift registers) to enable a nixie tube
pub const SELECT_BITS: [u8; 8] = [11, 10, 9, 8, 15, 14, 13, 12];

impl<I: Instance, R, const P1: char, const P2: char, const C: u8, const D: u8, const L: u8, const O: u8> Nixies<I, R, P1, P2, C, D, L, O> {

    // Writes bytes over the spi interface to the VFD shift registers
    fn spi_write(&mut self, words: &[u8], delay: &mut SysDelay) {
        let _ = self.spi_bus.write(words);

        // Latch data
        delay.delay_us(1u32);
        self.latch_pin.set_high();
        delay.delay_us(1u32);
        self.latch_pin.set_low();
    }

    // Turns off all nixie tubes
    pub fn turn_off(&mut self, delay: &mut SysDelay) {
        self.spi_write(&[0, 0, 0], delay);
    }

    // Writes a character to the specified nixie tube
    pub fn write_char(&mut self, character: char, nixie: usize, delay: &mut SysDelay) {

        // Get the bit which needs to be turned on inorder to display a matching character on the selected nixie tube
        let shift: usize = match character {
            '0' => 7,
            '1' => 18,
            '2' => 19,
            '3' => 20,
            '4' => 21,
            '5' => 22,
            '6' => 3,
            '7' => 4,
            '8' => 5,
            '9' => 6,
            '.' => 17,
            _ => 0,
        };

        // The only bits on in write_num are the shift bit and the nixie select bit
        let write_num: u32 = 1 << shift | 1 << SELECT_BITS[nixie];

        // Turn write num into 3 bytes to send over the spi interface
        // Send most significant bits first
        let write_words: &[u8] = &[
            (write_num >> 16) as u8,
            (write_num >> 8) as u8,
            write_num as u8
        ];

        self.spi_write(write_words, delay);
    }

    // Display a string slice on nixie tubes
    pub fn display_str(&mut self, string_slice: &str, delay: &mut SysDelay) {
        for (i, character) in string_slice.chars().enumerate() {
            self.write_char(character, i, delay);
            delay.delay_ms(1u16);
        }
    }
}

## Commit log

2024-04-08 Added final folder
    Added folder for the final design. Completed final schematic, ready for
    trace routing.
    [bom.csv, urd.kicad_pcb, urd.kicad_sch]
2024-04-11 Made PCB
    Routed all traces and panelized different boards.
    [bom.csv, urd.kicad_pcb, urd.kicad_sch]
2024-05-29 Redesign
    Switched to a modular design, so the the entire board doesn't have to be
    re-manufactured if there is a mistake.
    [bom.csv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]
2024-05-29 Added script to zip gerbers
    [microcontroller-B_Cu.gbr, microcontroller-B_Mask.gbr, microcontroller-B_Paste.gbr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]
2024-06-04 Added cad directory
    Added cad directory with initial design concept drawings
2024-06-05 Changed connectors
    Changed connector from mcu to power supply to idc.
    All switches now use a straight pinheader, with no pullups (now using
    mcu pulldowns).
    [microcontroller-B_Cu.gbr, microcontroller-B_Mask.gbr, microcontroller-B_Paste.gbr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]
2024-06-06 Added ESD protection
    Added esd protection to the mcu board.
    Also added breakout board for panel mounted switches.
    [mechanical_switch_breakout-B_Cu.gbr, mechanical_switch_breakout-B_Mask.gbr, mechanical_switch_breakout-B_Paste.gbr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]
2024-06-08 Added casing cad files
    Designed a case in Onshape, made minor revisions to breakout boards.
    [Urd.step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]
2024-06-09 Added vents to case
    Added vents to the underside of the case to encourage airflow.
    Also fixed some stupid design mistakes on the PCBs. This is the night
    before EMTH btw.
    [Urd.step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]
2024-06-16 Changed main PCB mount
    Changed nixie board pcb mount, so now screws are visible on the front
    side of the board instead of the back. Also changed mcu i2c pullups to
    2k2.
    [Urd.step, master_bom.csv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]
2024-06-19 Updated cad
    Moved pcb closer to front panel so nixies protrude more.
    [Urd.step]
2024-07-05 Updated cad
    Fixed heat insert hole clearances
    [Urd.step]
2024-07-12 Added embedded code
    Refactored project file structure, programmed embedded firmware for
    microcontroller. Made casing wider so idc connectors have enough
    clearance to plug in. Added laser cutting drawings to cad directory.
    [Urd.step, master_bom.csv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]
2024-07-13 Changed anti-poison pattern
    Made anti-poison routine light cathodes inorder, making a wave on each
    nixie tube. Additionally, stopped the clock from ticking when in time
    adjust mode.
2024-08-17 Changed pins Changed some pins around in the embedded software to match how I assembled the project.
